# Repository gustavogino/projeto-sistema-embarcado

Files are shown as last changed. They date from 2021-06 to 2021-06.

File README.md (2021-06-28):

# Projeto de Sistemas Embarcados (Apenas para aprendizagem)

Este projeto foi desenvolvido para aprender a criar um produto do zero, desde-o levantamento de requisitos, passando pelo diagrama de blocos, elaboração do esquema elétrico, criação da PCB de 2 layers (Placa de Circuito Impresso de duas camadas), o desenvolvimento do firmware do produto e por fim a documentação completa do projeto.

Esquema Elétrico:
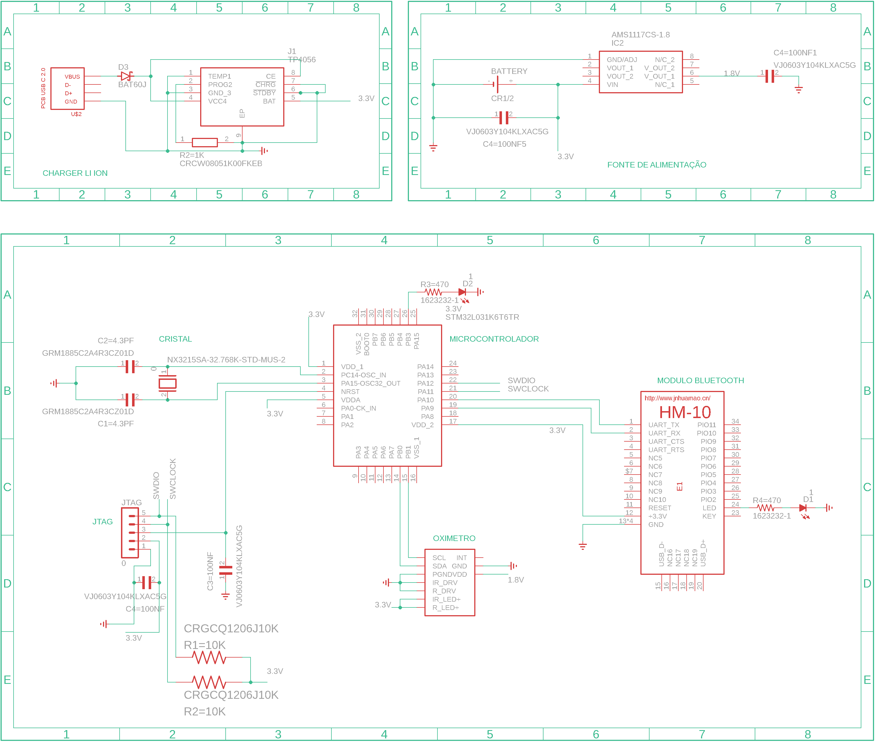
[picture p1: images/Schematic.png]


PCB lado TOP:
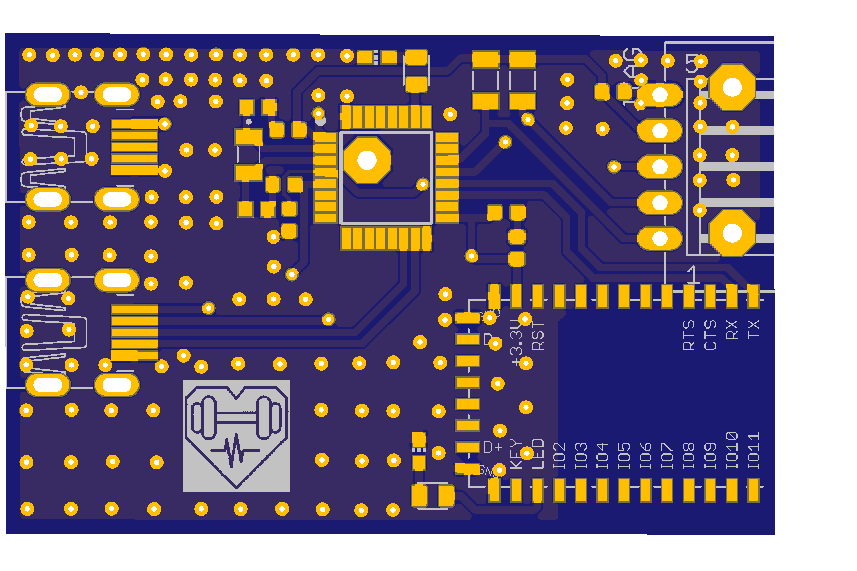
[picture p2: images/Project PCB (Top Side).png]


PCB lado Bottom:
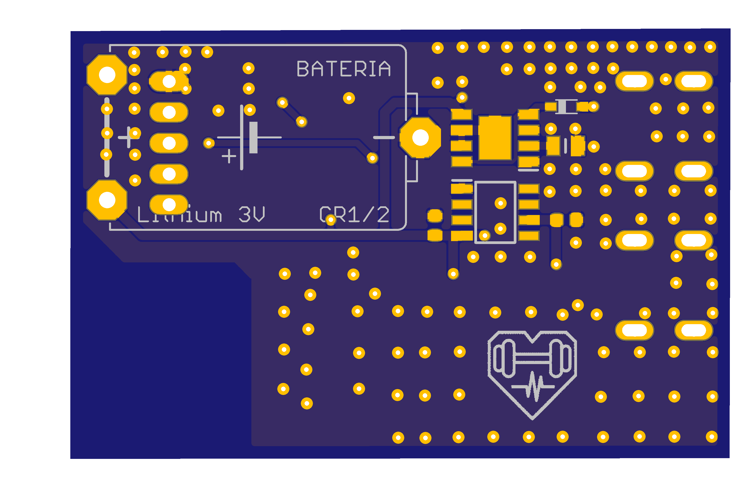
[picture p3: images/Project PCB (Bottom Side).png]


Os códigos fontes para verificação e alteração podem ser acessados nas suas respectivas pastas.

ATENÇÃO: Este projeto não foi fabricado de fato, apenas foi realizado para aprendizagem, não replique este produto para fins médicos, nenhuma garantia de funcionamento é fornecida. Utilize-o por sua conta e risco.

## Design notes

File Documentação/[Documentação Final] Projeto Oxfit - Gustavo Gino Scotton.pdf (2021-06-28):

Projeto: OXFIT

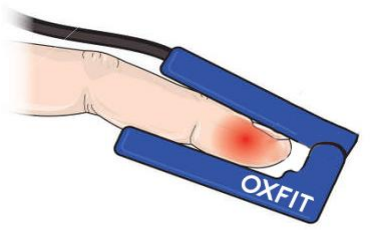
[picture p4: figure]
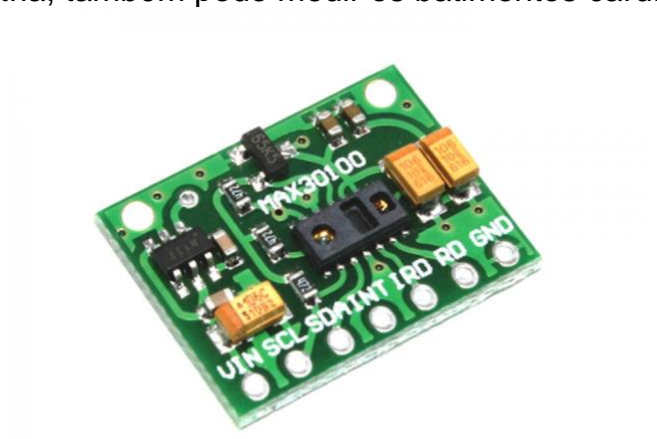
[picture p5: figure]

Projeto Oxport - Oxfit.doc | 1 de 9

Relatório Final

Projeto: OXPORT – Oxímetro Portátil | Data: 11/05/2021
Aluno: Gustavo Gino Scotton | Matrícula: 15201974

Descrição resumida
Aparelho para realizar oximetria (medir quanto oxigênio o sangue está transportando) com fins de utilização na área fitness. O aparelho será um apetrecho complementar ao atleta, onde poderá verificar por meio de um aplicativo mobile por conexão Bluetooth o relatório dos níveis de saturação do oxigênio e frequência cardíaca.

Visão geral
O oxigênio entra nos pulmões e depois é passado para o sangue. O sangue transporta oxigênio para os vários órgãos do nosso corpo. O principal meio pelo qual o oxigênio é transportado em nosso sangue é por meio da hemoglobina. Durante uma leitura de oximetria, um pequeno dispositivo semelhante a um prendedor de roupas é colocado no dedo.

Para realizar a coleta destes dados, o sensor MAX30100 foi utilizado, ele é capaz de além de medir a oximetria, também pode medir os batimentos cardíacos.

O sensor possui dois LEDs, um fotodetector, óptica otimizada e processamento de sinal analógico de baixo ruído para detectar sinais de pulso e frequência cardíaca. Ele opera com fontes de alimentação de 1,8 V e 3,3 V, para alimentar o sensor e os leds respectivamente.

Quando o coração bombeia sangue, há um aumento de hemoglobinas como resultado de ter mais sangue. À medida que o coração relaxa, o volume de sangue oxigenado também diminui. Conhecendo o tempo entre o aumento e a diminuição do sangue oxigenado, a taxa de batimentos cardíacos é determinada.

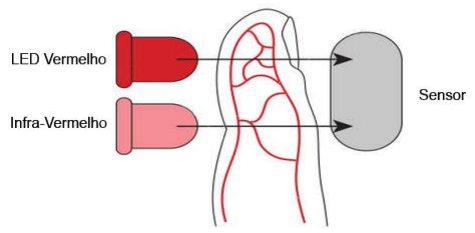
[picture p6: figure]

A ciência percebeu que o sangue oxigenado absorve mais luz infravermelha e passa mais luz vermelha, enquanto o sangue desoxigenado absorve a luz vermelha e passa mais luz infravermelha.

Esta é a principal função do MAX30100: ele lê os níveis de absorção de ambas as fontes de luz e os armazena em um buffer que pode ser lido via I2C pelo nosso microcontrolador.

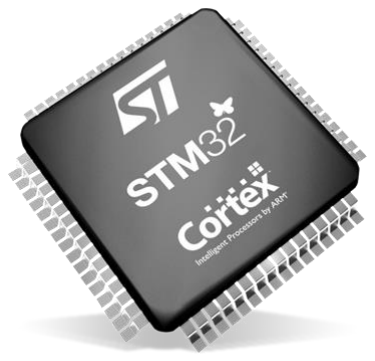
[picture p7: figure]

A família STM32 de microcontroladores de 32 bits com base no processador Arm Cortex M foi projetada para oferecer liberdade aos usuários de MCU.

Ele oferece soluções que combinam desempenho muito alto, recursos em tempo real, processamento de sinal digital, operação de baixa potência/baixa tensão e conectividade, enquanto mantém integração total e facilidade de desenvolvimento por possuir ferramentas que facilitam a vida do desenvolvedor.

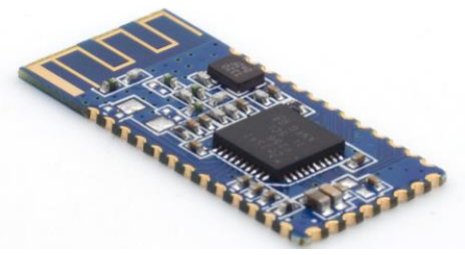
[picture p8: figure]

O HM-10 é um módulo Bluetooth 4.0 compatível com telefones Android e iOS. Além disso, possui um consumo baixo de energia por se tratar de um dispositivo BLE (Bluetooth Low Energy). Este módulo HM-10 pode ser configurado tanto como mestre, quanto com escravo, também necessita de nenhum circuito adicional para divisão de tensão nos pinos TX (transmissão de dados) e RX (recepção de dados), que operam em 3,3V.

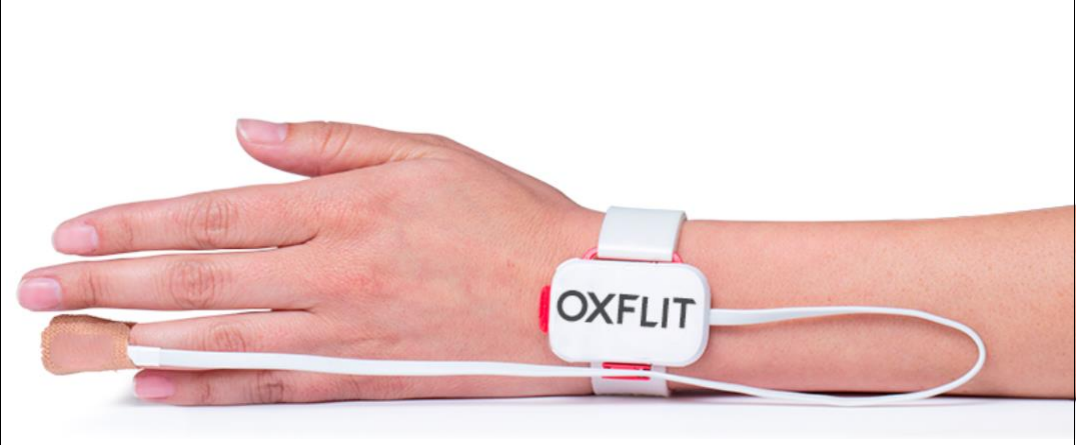
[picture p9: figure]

O dispositivo busca proporcionar total conforto ao seu utilizador durante as atividades físicas, sendo colocado em qualquer dedo da mão e tendo sua base fixo no punho, o que permite ao atleta uma maior impercepção do dispositivo.

O dispositivo é revestido de silicone, o que garante proteção contra respingos da agua, fazendo com que seu utilizador possa realizar seus exercicios fisicos também na de chuva.

O usuário define o inicio da gravação e o momento de parar, ou seja, inicia sua sessão de treino e a finaliza, recebendo o relatório em tempo real diretamente no dispositivo móvel atraves do bluetooth.

Embora o aplicativo móvel não esteja incluso neste projeto, o mesmo pode se conectar com um servidor através dos dados móveis, o que poderia fornecer estes dados para a equipe técnica do atleta realizar a analise em tempo real e poder retornar um feedback mais detalhado para o atleta com base nos relatórios recebidos, como por exemplo, a necessidade de respirar melhor/oxigenar mais em subidas de ladeiras.

Esse feedback em tempo real tornaria mais vantajoso os treinos, já que o atleta não precisaria terminar a volta para que a equipe técnica informe possíveis melhorias, tornando-se assim necessárias menos voltas para que o atleta adquira o ritmo ideal da respiração do circuito.

Projeto de Hardware

O hardware foi pensado para ser o menor possível, no formato adequado, pensando em se tornar atrativo ao atleta aderir seu uso.

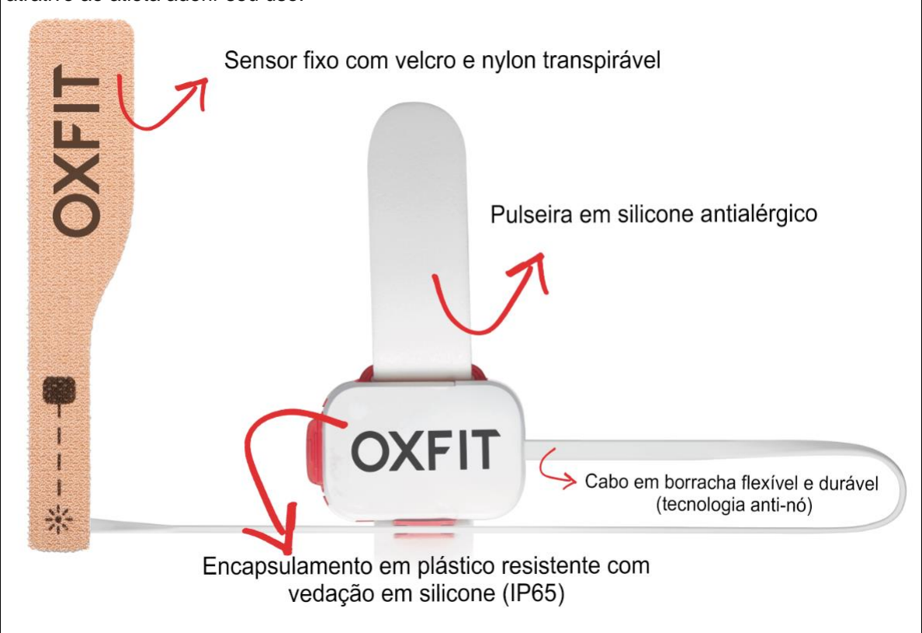
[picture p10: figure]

Possui o sensor fixo em uma fita de nylon e velcro, facilitando a fixação do dispositivo no dedo, e permitindo ao usuário definir o quão justo ele deseja.

Com uma pulseira em silicone antialérgico, torna-se extremamente leve, além de não segurar calor, o que impede que a região fique exposta a excesso de transpiração.

O cabo que conecta o sensor com a placa OXFIT, é em borracha extremamente resistente, seu designer retangular fornece uma maior resistência ao enrolamento involuntário do cabo, tornando-o menos propenso a ter nós no cabo.

O encapsulamento da placa OXFIT é feito de um polímero altamente resistente, com vedação em silicone, o que garante proteção contra respingos da água.

O projeto consiste em receber a entrada pelo dedo do usuário, fazendo com que o sensor MAX30100 faça a leitura dos dados de oxigenação sanguínea e frequência cardíaca e o envie para o microcontrolador através do protocolo I2C, este por sua vez, faz a leitura dos dados recebidos e envia via serial (UART) para o módulo Bluetooth que estará pareado com o celular a fim de fazer o envio dos dados e recebimento de comandos.

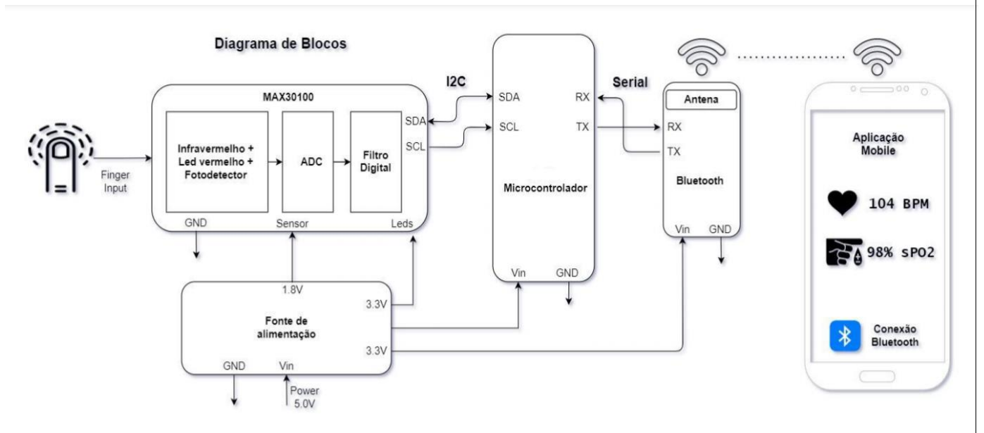
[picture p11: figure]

O sistema é alimentado por uma fonte de 3.3V, podendo ser diretamente alimentado via USB ou pela bateria interna de 160mAh o que garante uma enorme eficiência ao dispositivo.

A PCB foi elaborada para evitar quaisquer tipos de ruído externo, tendo sua alimentação focada no lado BOTTOM, e os sinais no lado TOP. Grande parte da área da placa é composta por um polígono de terra com furos de passagens para criar um grande GND.

A única área onde o polígono não avança é sobre a antena bluetooth a fim de evitar diminuir a potência do sinal.

Também possui trilhas paralelas e de espessura ideal, evitando a influencia de sinal entre trilhas.

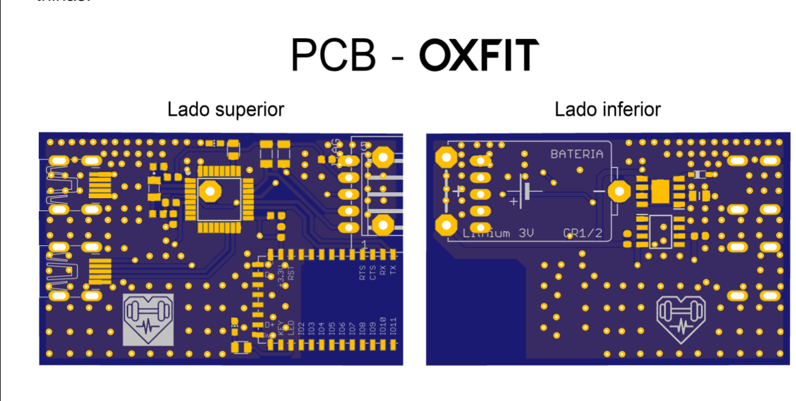
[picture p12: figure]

Por fim, imagem do esquema elétrico do projeto OXFIT é apresentada na próxima página.
É notável que em cada pino onde existe alimentação existem também seu capacitor de desacoplamento, tornando o sistema estável a oscilações de energia.

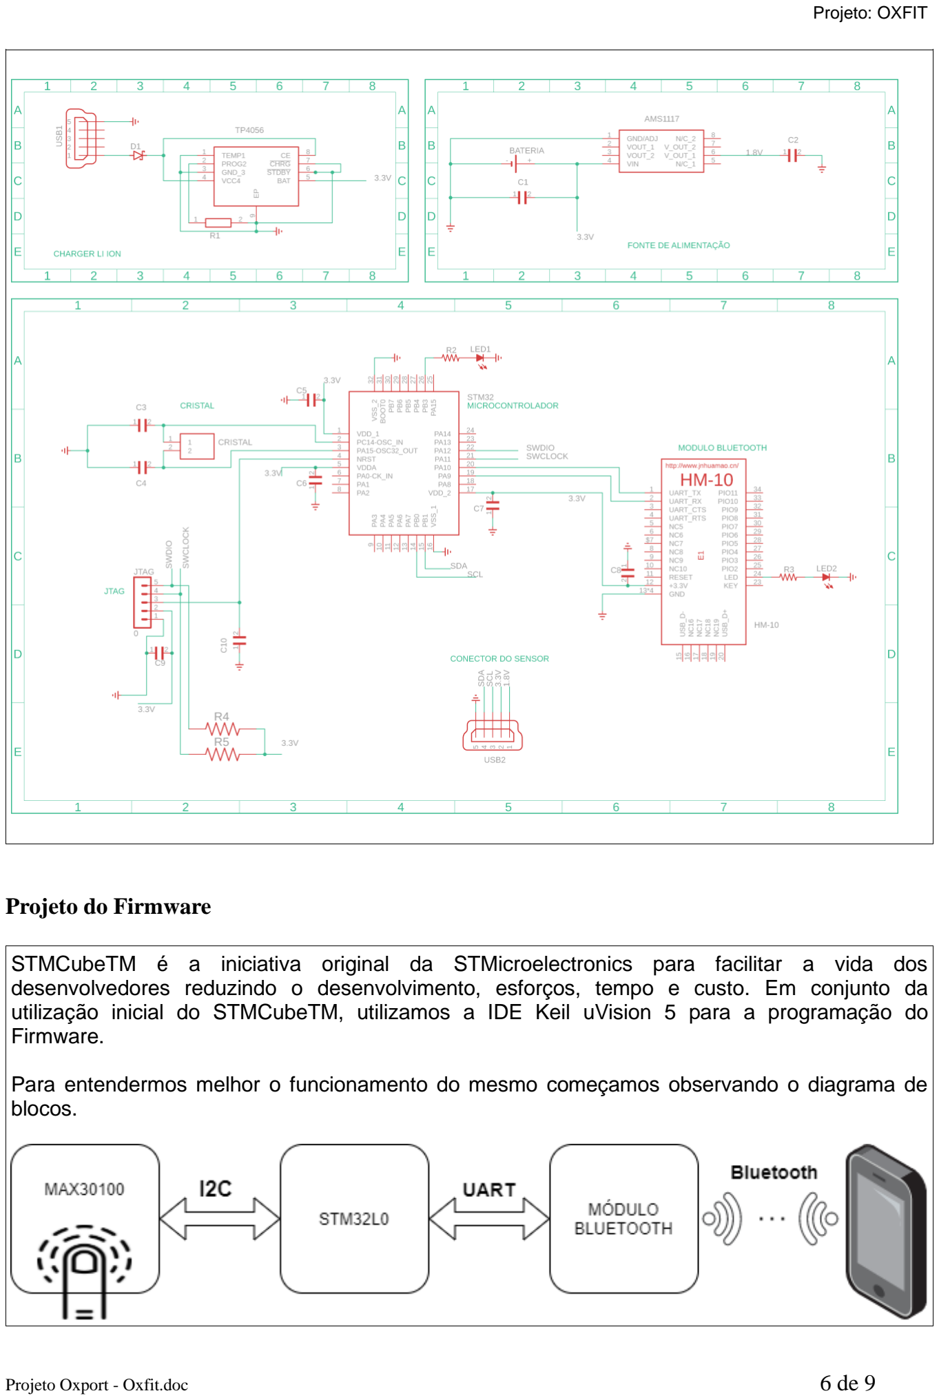
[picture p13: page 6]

Projeto do Firmware

STMCubeTM é a iniciativa original da STMicroelectronics para facilitar a vida dos desenvolvedores reduzindo o desenvolvimento, esforços, tempo e custo. Em conjunto da utilização inicial do STMCubeTM, utilizamos a IDE Keil uVision 5 para a programação do Firmware.

Para entendermos melhor o funcionamento do mesmo começamos observando o diagrama de blocos.

Informações:

- O Sensor MAX30100 se comunica com o microcontrolador STM32L0 pelo protocolo I2C.
- O Módulo Bluetooth se comunica serialmente com o STM32L0 através da UART.
- O Módulo Bluetooth por sua vez, envia dos dados para o dispositivo móvel conectado

Através da comunicação bluetooth o usuário pode realizar o envio de dois comandos distintos, além de receber os dados captados.

Vejamos o diagrama de casos de uso:

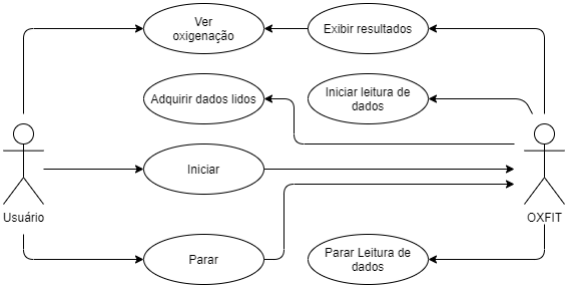
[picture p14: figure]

Os comandos que podem ser enviados são:

- Iniciar captura dos dados [Código: 1]
- Parar captura dos dados [Código: 0]

Em forma descritiva, o usuário pode solicitar ao Firmware OXFIT para iniciar ou parar a leitura de dados do sensor, onde este sim, irá envia a solicitação para que o sensor inicie a coleta dos dados, além de enviar uma espécie de ACK de confirmação para o dispositivo que fez a solicitação.

Quando o usuário realiza a operação, este sinal é enviado através do Bluetooth pela UART, desta forma então é lançado uma interrupção, nesta interrupção o microcontrolador analisa qual comando recebido (Iniciar / Parar), dependendo do comando, ações diferentes são tomadas pelo firmware.

Podemos detalhar melhor se analisarmos o diagrama de atividades, desta forma podemos ver o que cada dispositivo é responsável por fazer.

Neste diagrama de atividades, podemos ver quando o usuário envia seu sinal pelo dispositivo móvel e é recebido pelo Blueeoth que envia esta opção via UART para o microcontrolador.

O microcontrolador então analisa qual é a operação a ser seguida, sendo as seguintes duas possibilidades:
1. O sinal é para iniciar a coleta.
2. O sinal é para parar a coleta.

Caso seja a primeira opção, a mensagem recebida via UART deve ser código “1”, então o microcontrolador solicita via I2C que o sensor MAX30100 inicie a captura da oximetria e frequência cardíaca do usuário, além de definir em sua função principal a variável captura como verdadeira. Desta forma quando o sensor realizar a coleta dos dados e enviar para o microcontrolador, está função poderá claramente enviar os dados do buffer para o dispositivo móvel através do Bluetooth, finalizando assim o ciclo de envio, obviamente que isso fica em loop, mas apenas as atividades são mostradas aqui, para vermos detalhadamente o passo a passo vamos analisar o diagrama de sequencia após a conclusão deste tópico.

Caso seja a segunda opção, o microcontrolador recebe a informação via UART com o código “0”, como este comando é para desativar a coleta, ele envia esta solicitação para o dispositivo MAX30100 que é nosso sensor, fazendo com que a leitura de dados pare e assim seja poupada energia da bateria. Ao parar a coleta, o microcontrolador seta a variável de coleta como false, e define a saída de um pino GPIO que neste caso é um bluetooth. O status do led varia conforme a interrupção do timer.

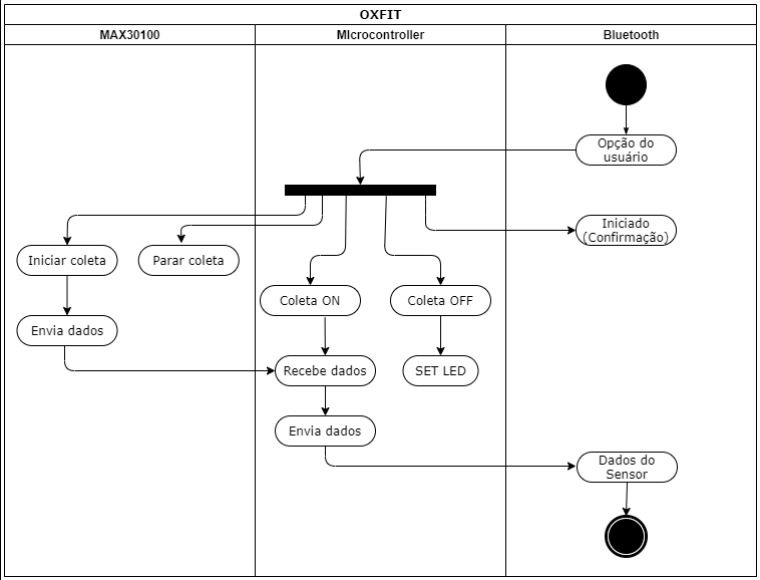
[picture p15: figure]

Agora que já foi possível entender os protocolos de comunicação através do diagrama de blocos, entender as funcionalidades de cada agente através do diagrama de casos de uso, e entender as atividades realizadas pelo firmware OXFIT, vamos agora ver o diagrama de sequência, que mostrara mais detalhamento o funcionamento e comunicação entre os blocos.

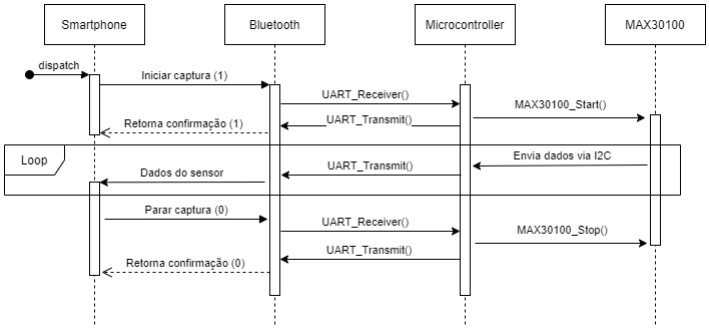
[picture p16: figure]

O Smartphone envia um comando via bluetooth, neste diagrama supomos o envio dos dois comandos na seguinte ordem:
1. Iniciar captura
2. Parar captura

Ao receber essa informação via bluetooth, gera uma interrupção da UART, então o microcontrolador recebe o dado e verifica qual é o comando (neste caso, para iniciar), desta forma ele inicia a coleta de dados pelo sensor e devolve a mesma mensagem para o bluetooth afim de criar uma confirmação de recebimento.

Após os passos anteriores entramos em um Loop da função main, onde o sensor MAX30100 envia dos dados via interrupção I2C, que são recebidos num buffer do microcontrolador e posteriormente é enviado para o bluetooth através da UART, chegando então via bluetooth para o smartphone. Este ciclo se repete até que uma nova interrupção da UART aconteça, neste caso, solicitando para parar a captura, veja o caso abaixo.

Caso o usuário solicite para parar a captura de dados, uma interrupção é lançada na UART, então o microcontrolador recebe o código deste comando e verifica que é para parar a captura, enviando assim um sinal para o sensor MAX30100 para ele parar a captura, deste modo, o sensor não envia mais os dados via I2C e consequentemente não gera mais interrupções ali.

Após enviar para o sensor parar a captura, o microcontrolador faz o envio do nosso ACK de confirmação de recebimento do comando através da UART, e por fim o smartphone acaba recebendo esta confirmação pelo bluetooth.

Lembrando que durante o loop, o usuário sempre está recebendo os dados, é dever do aplicativo mobile receber estes dados por bluetooth e realizar um pré-processamento, afim de mostrar ao usuário em uma interface amigável e agradável de navegar.

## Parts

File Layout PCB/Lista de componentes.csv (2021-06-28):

Part | Value | Device | Package | Description | ARROW_PART_NUMBER | ARROW_PRICE-STOCK | AVAILABILITY | COMMENT | DESCRIPTION | EU_ROHS_COMPLIANCE | HEIGHT | LABEL | MANUFACTURER_NAME | MANUFACTURER_PART_NUMBER | MF | MOUSER_PART_NUMBER | MOUSER_PRICE-STOCK | MP | MPN | OC_FARNELL | OC_NEWARK | PACKAGE | POPULARITY | POWER_RATING | PRICE | PURCHASE-URL | RESISTANCE | TOLERANCE | VOLTAGE_RATING
3.3V | STM32L031K6T6TR | STM32L031K6T6TR | QFP80P900X900X160-32N | STMICROELECTRONICS - STM32L031K6T6TR - ARM MCU, STM32 Family STM32L0 Series Microcontrollers, ARM Cortex-M0+, 32bit, 32 MHz, 32 KB, 8 KB | STM32L031K6T6TR | https://www.arrow.com/en/products/stm32l031k6t6tr/stmicroelectronics |  |  | STMICROELECTRONICS - STM32L031K6T6TR - ARM MCU, STM32 Family STM32L0 Series Microcontrollers, ARM Cortex-M0+, 32bit, 32 MHz, 32 KB, 8 KB |  | 1.6mm |  | STMicroelectronics | STM32L031K6T6TR |  | 511-STM32L031K6T6TR | https://www.mouser.co.uk/ProductDetail/STMicroelectronics/STM32L031K6T6TR/?qs=xwQlLnDx56Cmxri8cgW0QQ%3D%3D
BATERIA | CR1/2 | CR1/2 | CR1/2 | LI BATTERY Sonnenschein |  |  |  |  |  |  |  |  |  |  |  |  |  |  |  |  |  |  | 0
C1 | VJ0603Y104KLXAC5G | VJ0603Y104KLXAC5G | CAPC1608X92N | Multilayer Ceramic Capacitors MLCC - SMD/SMT 100nF 25volts 10% Check prices |  |  | Warning |  | Multilayer Ceramic Capacitors MLCC - SMD/SMT 100nF 25volts 10% |  |  |  |  |  | Vishay |  |  | VJ0603Y104KLXAC5G |  |  |  | 0603 Vishay |  |  | None | https://pricing.snapeda.com/search/part/VJ0603Y104KLXAC5G/?ref=eda
C2 | VJ0603Y104KLXAC5G | VJ0603Y104KLXAC5G | CAPC1608X92N | Multilayer Ceramic Capacitors MLCC - SMD/SMT 100nF 25volts 10% Check prices |  |  | Warning |  | Multilayer Ceramic Capacitors MLCC - SMD/SMT 100nF 25volts 10% |  |  |  |  |  | Vishay |  |  | VJ0603Y104KLXAC5G |  |  |  | 0603 Vishay |  |  | None | https://pricing.snapeda.com/search/part/VJ0603Y104KLXAC5G/?ref=eda
C3 | GRM1885C2A4R3CZ01D | GRM1885C2A4R3CZ01D | CAPC1608X90N | Check prices |  |  | Bad |  | 4.3pF ±0.25pF 100V Ceramic Capacitor C0G, NP0 0603 (1608 Metric) |  |  |  |  |  | Murata |  |  | GRM1885C2A4R3CZ01D |  |  |  | 1608 Murata |  |  | None
C4 | GRM1885C2A4R3CZ01D | GRM1885C2A4R3CZ01D | CAPC1608X90N | Check prices |  |  | Bad |  | 4.3pF ±0.25pF 100V Ceramic Capacitor C0G, NP0 0603 (1608 Metric) |  |  |  |  |  | Murata |  |  | GRM1885C2A4R3CZ01D |  |  |  | 1608 Murata |  |  | None
C5 | VJ0603Y104KLXAC5G | VJ0603Y104KLXAC5G | CAPC1608X92N | Multilayer Ceramic Capacitors MLCC - SMD/SMT 100nF 25volts 10% Check prices |  |  | Warning |  | Multilayer Ceramic Capacitors MLCC - SMD/SMT 100nF 25volts 10% |  |  |  |  |  | Vishay |  |  | VJ0603Y104KLXAC5G |  |  |  | 0603 Vishay |  |  | None | https://pricing.snapeda.com/search/part/VJ0603Y104KLXAC5G/?ref=eda
C6 | VJ0603Y104KLXAC5G | VJ0603Y104KLXAC5G | CAPC1608X92N | Multilayer Ceramic Capacitors MLCC - SMD/SMT 100nF 25volts 10% Check prices |  |  | Warning |  | Multilayer Ceramic Capacitors MLCC - SMD/SMT 100nF 25volts 10% |  |  |  |  |  | Vishay |  |  | VJ0603Y104KLXAC5G |  |  |  | 0603 Vishay |  |  | None | https://pricing.snapeda.com/search/part/VJ0603Y104KLXAC5G/?ref=eda
C7 | VJ0603Y104KLXAC5G | VJ0603Y104KLXAC5G | CAPC1608X92N | Multilayer Ceramic Capacitors MLCC - SMD/SMT 100nF 25volts 10% Check prices |  |  | Warning |  | Multilayer Ceramic Capacitors MLCC - SMD/SMT 100nF 25volts 10% |  |  |  |  |  | Vishay |  |  | VJ0603Y104KLXAC5G |  |  |  | 0603 Vishay |  |  | None | https://pricing.snapeda.com/search/part/VJ0603Y104KLXAC5G/?ref=eda
C8 | VJ0603Y104KLXAC5G | VJ0603Y104KLXAC5G | CAPC1608X92N | Multilayer Ceramic Capacitors MLCC - SMD/SMT 100nF 25volts 10% Check prices |  |  | Warning |  | Multilayer Ceramic Capacitors MLCC - SMD/SMT 100nF 25volts 10% |  |  |  |  |  | Vishay |  |  | VJ0603Y104KLXAC5G |  |  |  | 0603 Vishay |  |  | None | https://pricing.snapeda.com/search/part/VJ0603Y104KLXAC5G/?ref=eda
C9 | VJ0603Y104KLXAC5G | VJ0603Y104KLXAC5G | CAPC1608X92N | Multilayer Ceramic Capacitors MLCC - SMD/SMT 100nF 25volts 10% Check prices |  |  | Warning |  | Multilayer Ceramic Capacitors MLCC - SMD/SMT 100nF 25volts 10% |  |  |  |  |  | Vishay |  |  | VJ0603Y104KLXAC5G |  |  |  | 0603 Vishay |  |  | None | https://pricing.snapeda.com/search/part/VJ0603Y104KLXAC5G/?ref=eda
C10 | VJ0603Y104KLXAC5G | VJ0603Y104KLXAC5G | CAPC1608X92N | Multilayer Ceramic Capacitors MLCC - SMD/SMT 100nF 25volts 10% Check prices |  |  | Warning |  | Multilayer Ceramic Capacitors MLCC - SMD/SMT 100nF 25volts 10% |  |  |  |  |  | Vishay |  |  | VJ0603Y104KLXAC5G |  |  |  | 0603 Vishay |  |  | None | https://pricing.snapeda.com/search/part/VJ0603Y104KLXAC5G/?ref=eda
CRISTAL | NX3215SA-32.768K-EXS00A-MU0000 | NX3215SA-32.768K-EXS00A-MU0000 | NX3215SA32768KEXS00AMU00003 | Crystals CRYSTAL 32.768KHZ 12.5PF SMD |  |  |  |  | Crystals CRYSTAL 32.768KHZ 12.5PF SMD |  | 0.9mm |  | NDK | NX3215SA-32.768K-EXS00A-MU00003 |  | 344-NX3215SA32.768K3 | https://www.mouser.co.uk/ProductDetail/NDK/NX3215SA-32768K-EXS00A-MU00003?qs=w%2Fv1CP2dgqrE9YNksyAN9A%3D%3D
D1 | BAT60J | BAT60J | SOD323_ST | Schottky barrier diode |  |  |  |  |  |  |  |  |  |  |  |  |  |  |  |  |  |  | 7
E1 | HM-10-BOARD | HM-10-BOARD | 26.9X13X2.2_BOARD | HM Bluetooth module use TI CC2540 or CC2541, Master and slave roles in one, transmission version and remote control version and PIO state acquisition functions in one, Support the AT command modify module parameters, Convenient and flexible.
IC2 | AMS1117CS-1.8 | AMS1117CS-1.8 | SOIC127P599X175-8N | 1A LOW DROPOUT VOLTAGE REGULATOR |  |  |  |  | 1A LOW DROPOUT VOLTAGE REGULATOR |  | 1.752mm |  | Advanced Monolithic Systems | AMS1117CS-1.8
J1 | TP4056 | TP4056 | SOIC127P600X175-9N | 1A Standalone Linear Li-lon Battery Charger, SOP-8 |  |  |  |  | 1A Standalone Linear Li-lon Battery Charger, SOP-8 |  | 1.75mm |  | NanJing Top Power | TP4056
JTAG | 0 | L05P | L05P | AMP MT CONNECTOR |  |  |  |  |  |  |  |  |  |  |  |  |  |  |  | unknown | unknown |  | 0
LED1 | 1 | LED_LEDCHIP-LED0603MP | LED_CHIP-LED0603MP | LED
LED2 | 1 | LED_LEDCHIP-LED0603MP | LED_CHIP-LED0603MP | LED
MINI_USB | MINI-USB_SHIELD5P4-32005-501 | MINI-USB_SHIELD5P4-32005-501 | 32005-501 | MINI USB-B R/A W/O POST 5 pol. |  |  |  |  |  |  |  |  |  |  |  |  |  |  |  | unknown | unknown |  | 0
R1 | CRCW08051K00FKEB | CRCW08051K00FKEB | RESC2012X50N | VISHAY - CRCW08051K00FKEB - RES, THICK FILM, 1K, 1%, 0.125W, 0805, REEL | CRCW08051K00FKEB | https://www.arrow.com/en/products/crcw08051k00fkeb/vishay |  |  | VISHAY - CRCW08051K00FKEB - RES, THICK FILM, 1K, 1%, 0.125W, 0805, REEL |  | 0.5mm |  | Vishay | CRCW08051K00FKEB |  | 71-CRCW08051K00FKEB | https://www.mouser.co.uk/ProductDetail/Vishay-Dale/CRCW08051K00FKEB/?qs=DZvKvnD5UYWgZ7Jd5X5uKQ%3D%3D
R2 | 1623232-1 | 1623232-1 | RESC2012X65N | CRG0805 1% 470R Check prices |  |  | Warning | 1623232-1 | 470 Ohms ±1% 0.125W, 1/8W Chip Resistor 0805 (2012 Metric) Thick Film | Compliant with Exemptions |  |  |  |  | TE Connectivity |  |  | 1623232-1 |  |  |  | 0805 |  | .125 W | None |  | 470 | 1% | 150 V
R3 | 1623232-1 | 1623232-1 | RESC2012X65N | CRG0805 1% 470R Check prices |  |  | Warning | 1623232-1 | 470 Ohms ±1% 0.125W, 1/8W Chip Resistor 0805 (2012 Metric) Thick Film | Compliant with Exemptions |  |  |  |  | TE Connectivity |  |  | 1623232-1 |  |  |  | 0805 |  | .125 W | None |  | 470 | 1% | 150 V
R4 | CRGCQ1206J10K | CRGCQ1206J10K | RESC3115X65N | Fixed Resistor CRGCQ 1206 10K 5% Check prices |  |  | Warning | 2-2176344-5 | Fixed Resistor CRGCQ 1206 10K 5% |  |  |  |  |  | TE Connectivity |  |  | CRGCQ1206J10K |  |  |  | 3115 TE Connectivity |  |  | None | https://pricing.snapeda.com/search/part/CRGCQ1206J10K/?ref=eda
R5 | CRGCQ1206J10K | CRGCQ1206J10K | RESC3115X65N | Fixed Resistor CRGCQ 1206 10K 5% Check prices |  |  | Warning | 2-2176344-5 | Fixed Resistor CRGCQ 1206 10K 5% |  |  |  |  |  | TE Connectivity |  |  | CRGCQ1206J10K |  |  |  | 3115 TE Connectivity |  |  | None | https://pricing.snapeda.com/search/part/CRGCQ1206J10K/?ref=eda
USB1 | MINI-USB_SHIELD5P4-32005-501 | MINI-USB_SHIELD5P4-32005-501 | 32005-501 | MINI USB-B R/A W/O POST 5 pol. |  |  |  |  |  |  |  |  |  |  |  |  |  |  |  | unknown | unknown |  | 0

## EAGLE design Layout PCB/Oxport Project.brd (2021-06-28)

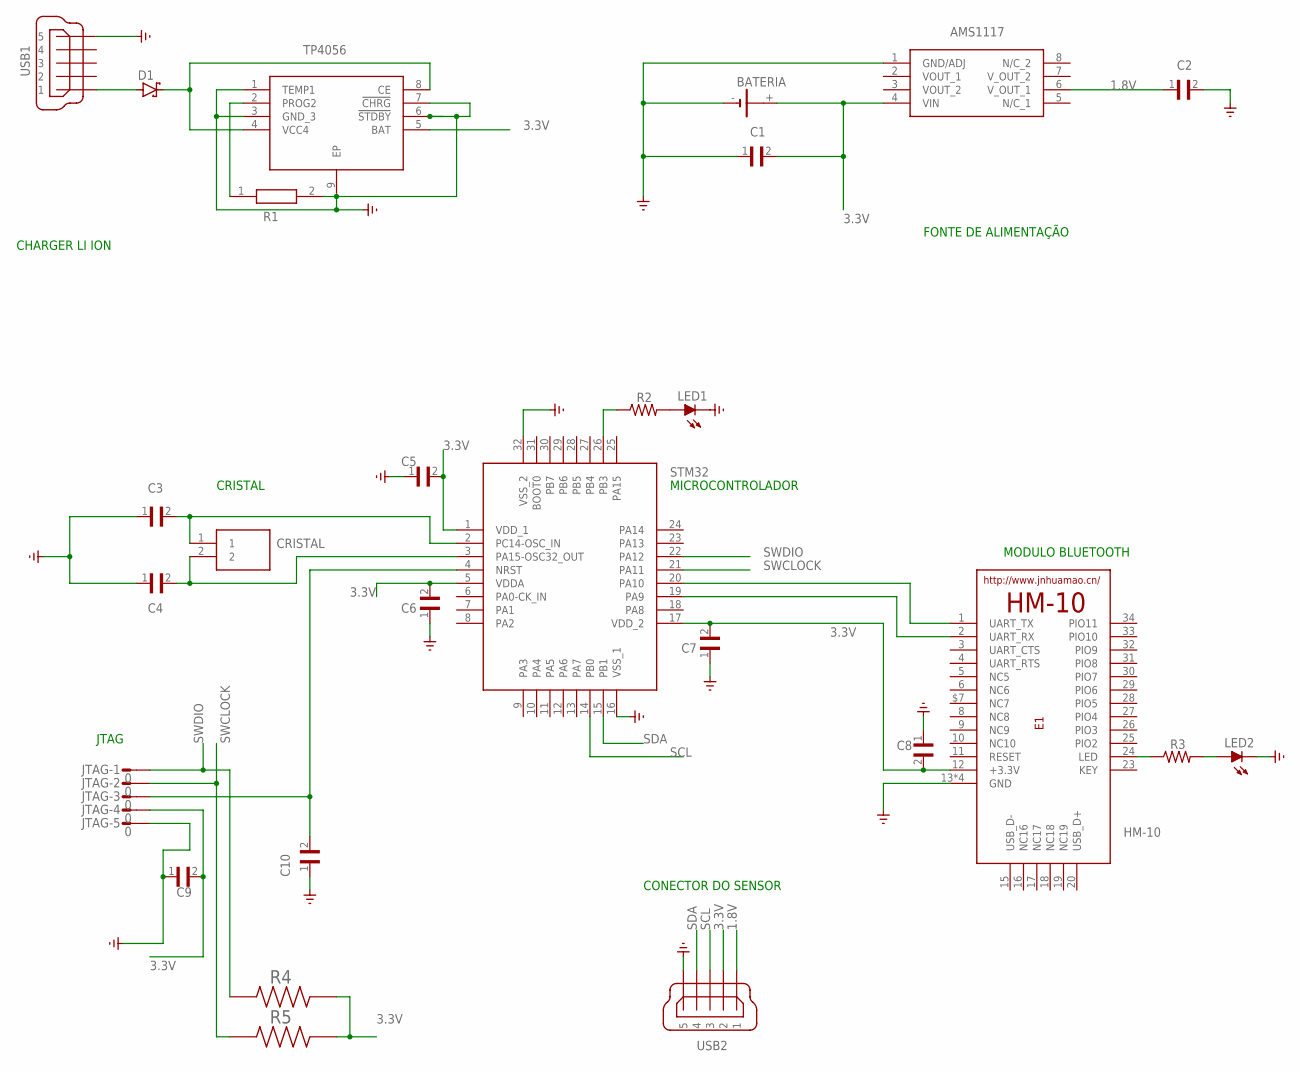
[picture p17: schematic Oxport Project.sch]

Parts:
3.3V: STM32L031K6T6TR; QFP80P900X900X160-32N
BATERIA: CR1/2
C1, C2, C5, C6, C7, C8, C9, C10: VJ0603Y104KLXAC5G; CAPC1608X92N
C3, C4: GRM1885C2A4R3CZ01D; CAPC1608X90N
CRISTAL: NX3215SA-32.768K-EXS00A-MU0000; NX3215SA32768KEXS00AMU00003
D1: BAT60J; SOD323_ST
E1: HM-10-BOARD; 26.9X13X2.2_BOARD
IC2: AMS1117CS-1.8; SOIC127P599X175-8N
J1: TP4056; SOIC127P600X175-9N
JTAG: 0; L05P
LED1, LED2: 1; LED_CHIP-LED0603MP
MINI_USB: MINI-USB_SHIELD5P4-32005-501; 32005-501
R1: CRCW08051K00FKEB; RESC2012X50N
R2, R3: 1623232-1; RESC2012X65N
R4, R5: CRGCQ1206J10K; RESC3115X65N
USB1: MINI-USB_SHIELD5P4-32005-501; 32005-501

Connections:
1.8V: C2.1, IC2.6 (V_OUT_1), USB1.1
3.3V: 3.3V.1 (VDD_1), 3.3V.5 (VDDA), 3.3V.17 (VDD_2), BATERIA.+, C1.2, C5.2, C6.2, C7.2, C8.2, C9.2, E1.12 (+3.3V), IC2.4 (VIN), J1.5 (BAT), JTAG.4, R4.2, R5.2, USB1.2
GND: 3.3V.16 (VSS_1), 3.3V.32 (VSS_2), BATERIA.-, C1.1, C2.2, C3.1, C4.1, C5.1, C6.1, C7.1, C8.1, C9.1, C10.1, E1.13 (GND), E1.14 (GND), E1.21 (GND), E1.22 (GND), IC2.1 (GND/ADJ), J1.1 (TEMP1), J1.3 (GND_3), J1.6 (!STDBY), J1.7 (!CHRG), J1.9 (EP), JTAG.5, LED1.C, LED2.C, MINI_USB.5, R1.2, USB1.5
unnamed: D1.A, MINI_USB.1
unnamed: 3.3V.2 (PC14-OSC_IN), C3.2, CRISTAL.1
unnamed: 3.3V.3 (PA15-OSC32_OUT), C4.2, CRISTAL.2
unnamed: 3.3V.20 (PA10), E1.1 (UART_TX)
unnamed: 3.3V.19 (PA9), E1.2 (UART_RX)
unnamed: 3.3V.26 (PB3), R2.1
unnamed: E1.24 (LED), R3.1
unnamed: LED2.A, R3.2
unnamed: LED1.A, R2.2
unnamed: D1.C, J1.4 (VCC4), J1.8 (CE)
unnamed: J1.2 (PROG2), R1.1
RESET: 3.3V.4 (NRST), C10.2, JTAG.3
SCL: 3.3V.14 (PB0), USB1.3
SDA: 3.3V.15 (PB1), USB1.4
SWCLOCK: 3.3V.21 (PA11), JTAG.2, R5.1
SWDIO: 3.3V.22 (PA12), JTAG.1, R4.1

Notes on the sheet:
CHARGER LI ION
FONTE DE ALIMENTAÇÃO
MICROCONTROLADOR
MODULO BLUETOOTH
JTAG
CRISTAL
CONECTOR DO SENSOR
USB1
USB2
STM32
HM-10
AMS1117

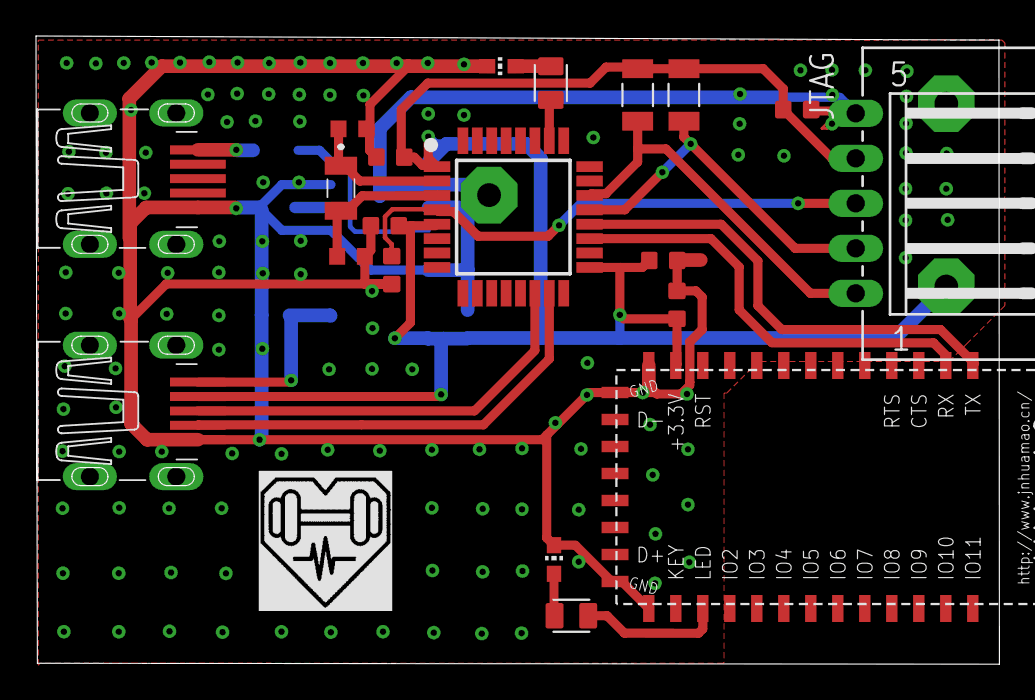
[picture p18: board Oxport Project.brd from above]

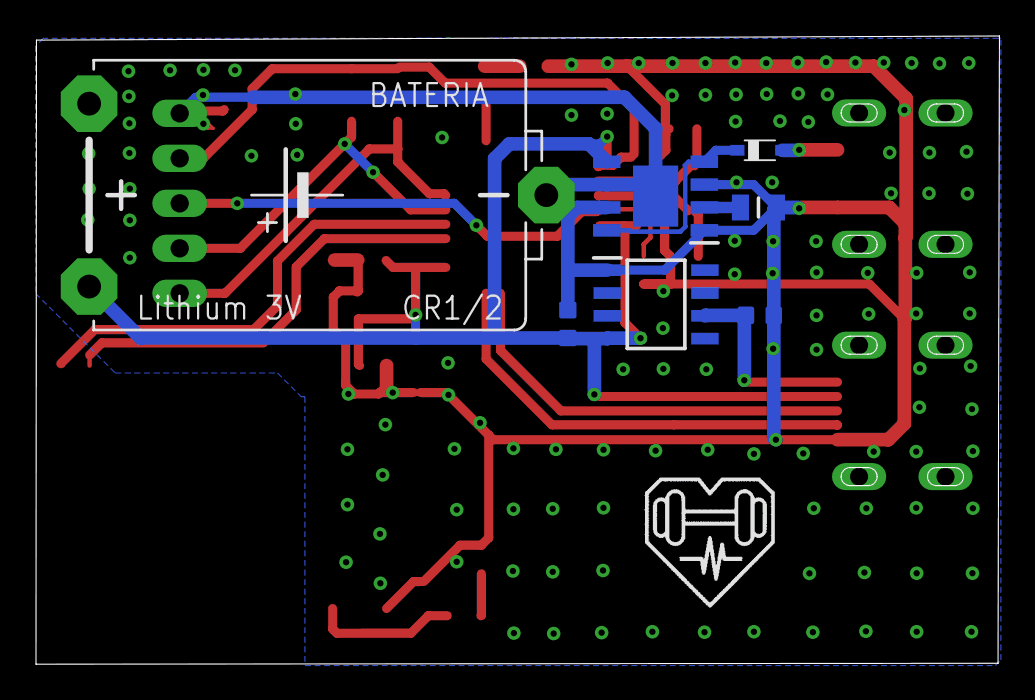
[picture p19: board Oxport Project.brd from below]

Board: 2 copper layers, 53.5 x 34.9 mm, 27 parts (7 on the bottom side), 19 nets.

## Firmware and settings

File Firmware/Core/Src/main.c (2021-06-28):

#include "main.h"
#include "project_hal.h"
#include "functions.h"

#define MAX30100_I2C_ADDRESS 	0xAE
#define TIMEOUT 100

uint8_t RX_BLE_BUFFER[2] = {0};
uint8_t SENSOR_DATA_BUFFER[100] = {0};

STATUS CAPTURE = OFF;
GPIO_PinState LED_STATE = GPIO_PIN_RESET;

int main(void)
{	
	START_HAL();
	CONFIG_CLOCK();
	START_GPIO();
	START_I2C();
	START_TIMER();
	START_UART();
	START_MAX30100();
	
	UART_Receive(RX_BLE_BUFFER);
	
  while (1)
	{
			if			(RX_BLE_BUFFER[0] == '0')	CAPTURE = OFF;  	
    	else if	(RX_BLE_BUFFER[0] == '1')	CAPTURE = ON;
		
			switch(CAPTURE)
			{
				case OFF:
					WritePin(LED_PIN_GPIO_Port, LED_PIN, LED_STATE);					
					break;
				
				case ON:					
					UART_Transmit(SENSOR_DATA_BUFFER, TIMEOUT);
					break;					
			}
			Sleep_ms(100);
  }
}

void Interruption_TIM2(void)
{	
	LED_STATE = (LED_STATE == GPIO_PIN_SET) ? GPIO_PIN_RESET : GPIO_PIN_SET;
}

void Interruption_UART(void)
{
	UART_Receive(RX_BLE_BUFFER);	
	RX_BLE_BUFFER[0] == '1' ? MAX30100_Start() : MAX30100_Stop(); 	
	UART_Transmit(RX_BLE_BUFFER, TIMEOUT);	
}

void Interruption_I2C(void)
{
	I2C_Receive(MAX30100_I2C_ADDRESS, SENSOR_DATA_BUFFER);
}

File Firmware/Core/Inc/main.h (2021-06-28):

#ifndef __MAIN_H
#define __MAIN_H

#ifdef __cplusplus
extern "C" {
#endif

#include "stm32l0xx_hal.h"

#define I2C_SCL_SENSOR_Pin 					GPIO_PIN_9
#define I2C_SDA_SENSOR_Pin 					GPIO_PIN_10
#define LED_PIN											GPIO_PIN_15

#define I2C_SDA_SENSOR_GPIO_Port 		GPIOA
#define I2C_SCL_SENSOR_GPIO_Port 		GPIOA
#define LED_PIN_GPIO_Port 					GPIOA

typedef enum
{
  OFF = 0,
  ON
} STATUS;

void Interruption_TIM2(void);
void Interruption_UART(void);
void Interruption_I2C(void);

#ifdef __cplusplus
}
#endif

#endif
